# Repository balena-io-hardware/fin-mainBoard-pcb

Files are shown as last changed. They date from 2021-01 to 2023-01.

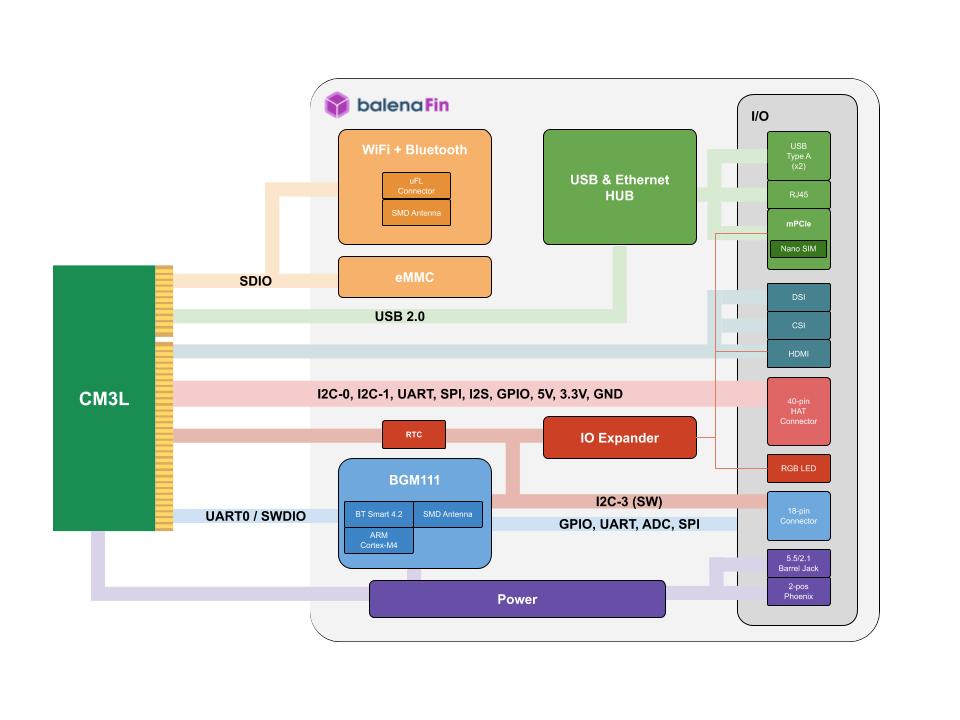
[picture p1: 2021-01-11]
Documentation/Block-diagram.jpg

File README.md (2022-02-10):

# balena-fin-pcb-legacy
balenaFin v1.x.x PCB repository

## OrCAD environment setup.

In order to get the proper poligon layout, the following parameters need to be set on "Global Dynamic Shape Parameters":

Under "Thermal relief connects" tab:
- Thru pin -> Full contact -> Minimum connections: 2
- Thru pin -> Full contact -> Maximum connections: 4
- SMD pin -> Orthogonal -> Maximum connections: 4
- SMD pin -> Orthogonal -> Maximum connections: 4
- Vias-> Full contact -> Maximum connections: 4
- Vias -> Full contact -> Maximum connections: 4
* In every case, "Best contact" should NOT be ticked.

- Select "Use fixed thermal width of": 0.2
* "Use xhatch thermal width" should be NOT ticked.

Under "Clearances" tab:
- Thru pin -> Thermal/ant -> Oversize value: 0.1
- SMD pin -> Thermal/ant -> Oversize value: 0.1
- Via -> Thermal/ant -> Oversize value: 0.1
- Line/cline -> (DRC) -> 0.0
- Text -> (DRC) -> 0.0
- Shape/rect -> (DRC) -> 0.0

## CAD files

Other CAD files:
Documentation/topographic/TOPOBOTTOM.dxf
Documentation/topographic/TOPOTOP.DXF
Source/bga-88-lead-round.psm
Source/bga-88-lead.psm
Source/bga-88-round.psm
Source/emi_filter.psm

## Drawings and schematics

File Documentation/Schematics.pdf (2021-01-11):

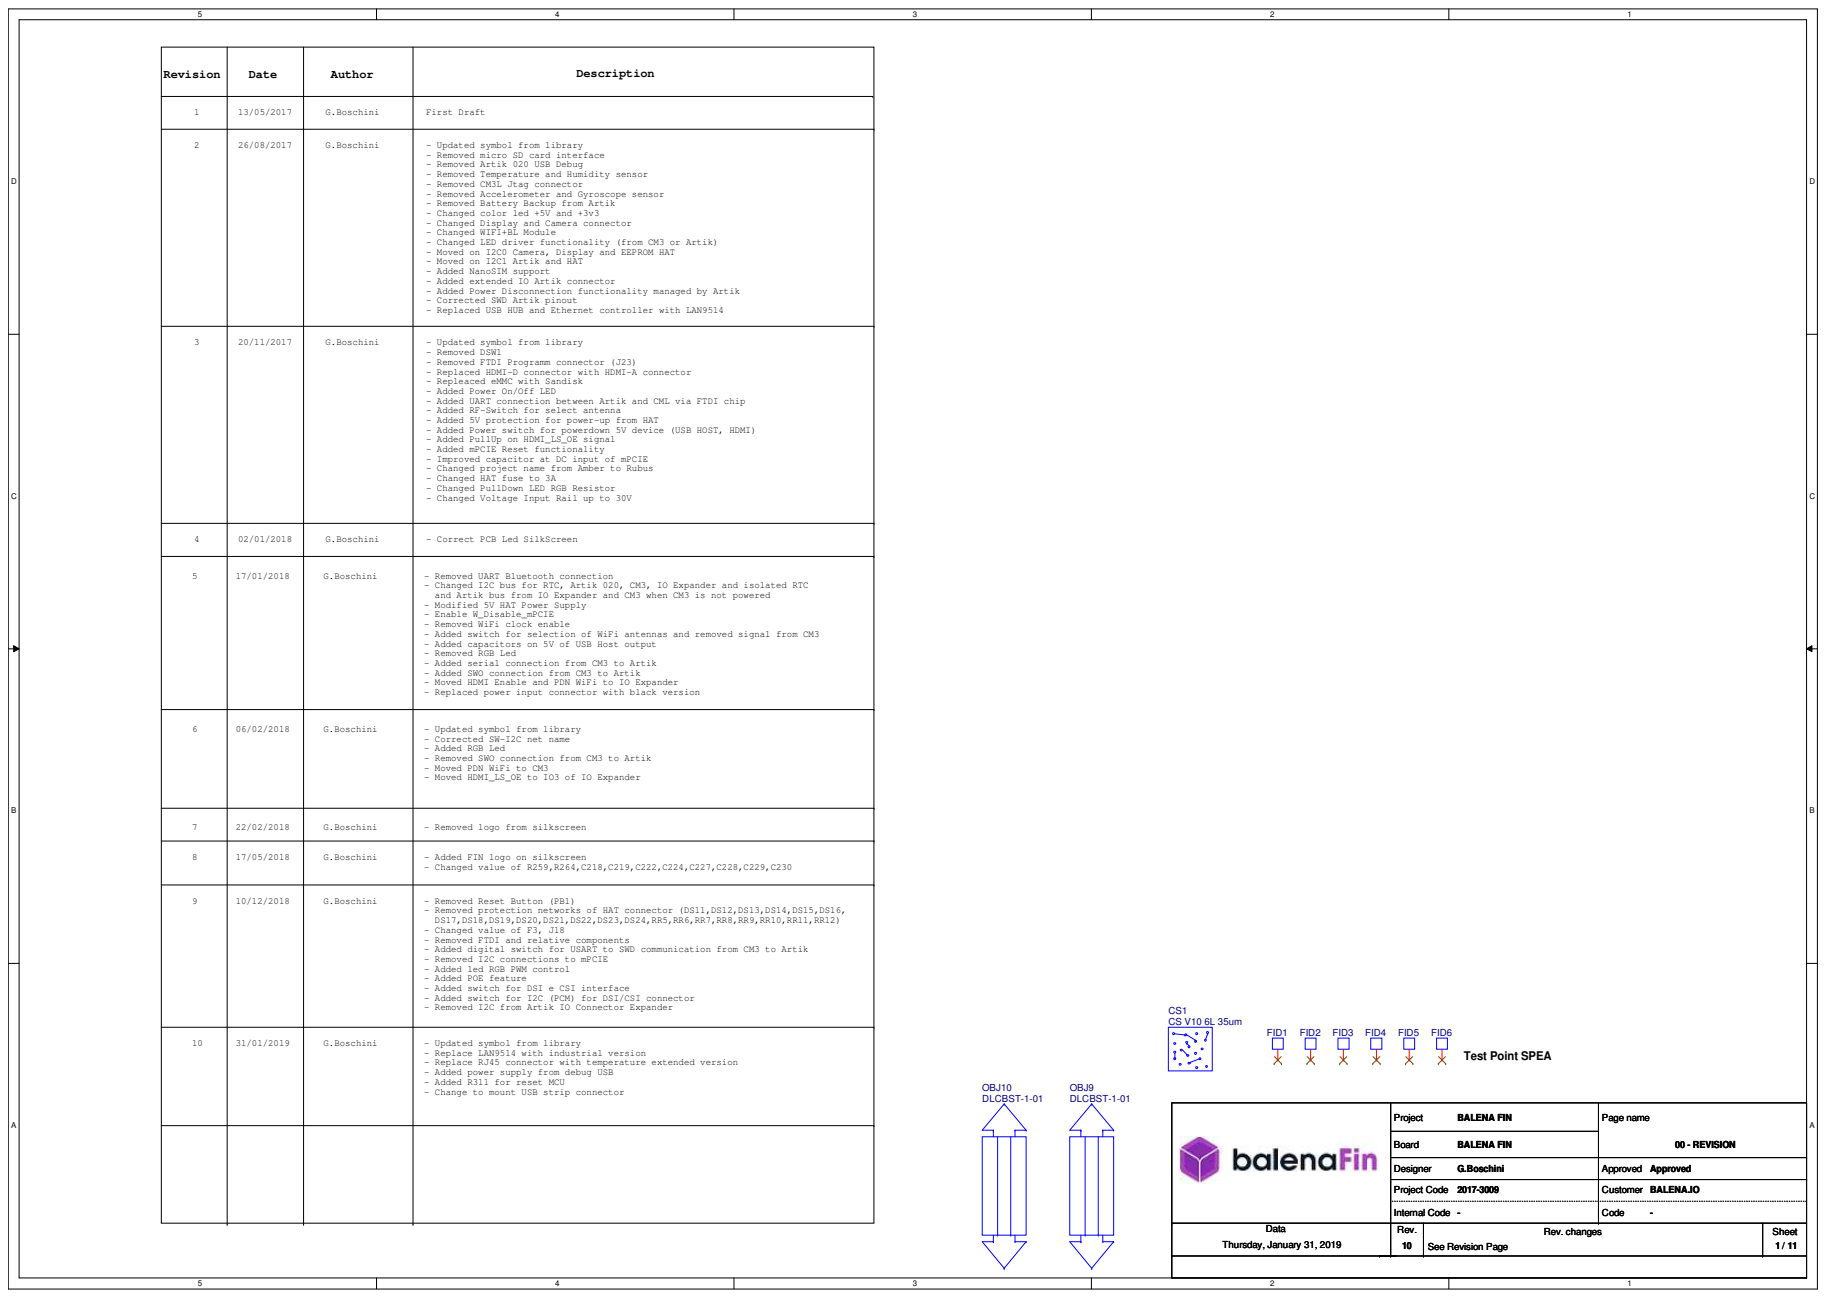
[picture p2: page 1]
Revision; Date; Author; Description; G.Boschini; First Draft; 2 G.Boschini 26/08/2017; - Updated symbol from library G.Boschini; G.Boschini 02/01/2018; - Correct PCB Led SilkScreen; - Removed UART Bluetooth connection G.Boschini; G.Boschini 06/02/2018; - Updated symbol from library; - Removed logo from silkscreen G.Boschini; - Removed Reset Button (PB1); 9 G.Boschini; - Added FIN logo on silkscreen; 8 G.Boschini; Rev.; Rev. changes; Sheet; Board; Project; Code; Page name; Data; Internal Code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

- Updated symbol from library
- Removed micro SD card interface
- Removed Artik 020 USB Debug
- Removed Temperature and Humidity sensor
- Removed CM3L Jtag connector
- Removed Accelerometer and Gyroscope sensor
- Removed Battery Backup from Artik
- Changed color led +5V and +3v3
- Changed Display and Camera connector
- Changed WIFI+BL Module
- Changed LED driver functionality (from CM3 or Artik)
- Moved on I2C0 Camera, Display and EEPROM HAT
- Moved on I2C1 Artik and HAT
- Added NanoSIM support
- Added extended IO Artik connector
- Added Power Disconnection functionality managed by Artik
- Corrected SWD Artik pinout
- Replaced USB HUB and Ethernet controller with LAN9514

- Removed DSW1
- Removed FTDI Programm connector (J23)
- Replaced HDMI-D connector with HDMI-A connector
- Repleaced eMMC with Sandisk
- Added Power On/Off LED
- Added UART connection between Artik and CML via FTDI chip
- Added RF-Switch for select antenna
- Added 5V protection for power-up from HAT
- Added Power switch for powerdown 5V device (USB HOST, HDMI)
- Added PullUp on HDMI_LS_OE signal
- Added mPCIE Reset functionality
- Improved capacitor at DC input of mPCIE
- Changed project name from Amber to Rubus
- Changed HAT fuse to 3A
- Changed PullDown LED RGB Resistor
- Changed Voltage Input Rail up to 30V

- Changed I2C bus for RTC, Artik 020, CM3, IO Expander and isolated RTC
and Artik bus from IO Expander and CM3 when CM3 is not powered
- Modified 5V HAT Power Supply
- Enable W_Disable_mPCIE
- Removed WiFi clock enable
- Added switch for selection of WiFi antennas and removed signal from CM3
- Added capacitors on 5V of USB Host output
- Removed RGB Led
- Added serial connection from CM3 to Artik
- Added SWO connection from CM3 to Artik
- Moved HDMI Enable and PDN WiFi to IO Expander
- Replaced power input connector with black version

- Corrected SW-I2C net name
- Added RGB Led
- Removed SWO connection from CM3 to Artik
- Moved PDN WiFi to CM3
- Moved HDMI_LS_OE to IO3 of IO Expander

- Changed value of R259,R264,C218,C219,C222,C224,C227,C228,C229,C230

- Removed protection networks of HAT connector (DS11,DS12,DS13,DS14,DS15,DS16,
- Changed value of F3, J18
- Removed FTDI and relative components
- Added digital switch for USART to SWD communication from CM3 to Artik
- Removed I2C connections to mPCIE
- Added led RGB PWM control
- Added POE feature
- Added switch for DSI e CSI interface
- Added switch for I2C (PCM) for DSI/CSI connector
- Removed I2C from Artik IO Connector Expander

- Replace LAN9514 with industrial version
- Replace RJ45 connector with temperature extended version
- Added power supply from debug USB
- Added R311 for reset MCU
- Change to mount USB strip connector

Test Point SPEA

Designer Designer Designer G.Boschini G.Boschini G.Boschini | Approved Approved Approved

Project Code Project Code Project Code 2017-3009 2017-3009 2017-3009 | Customer Customer Customer BALENA.IO BALENA.IO BALENA.IO

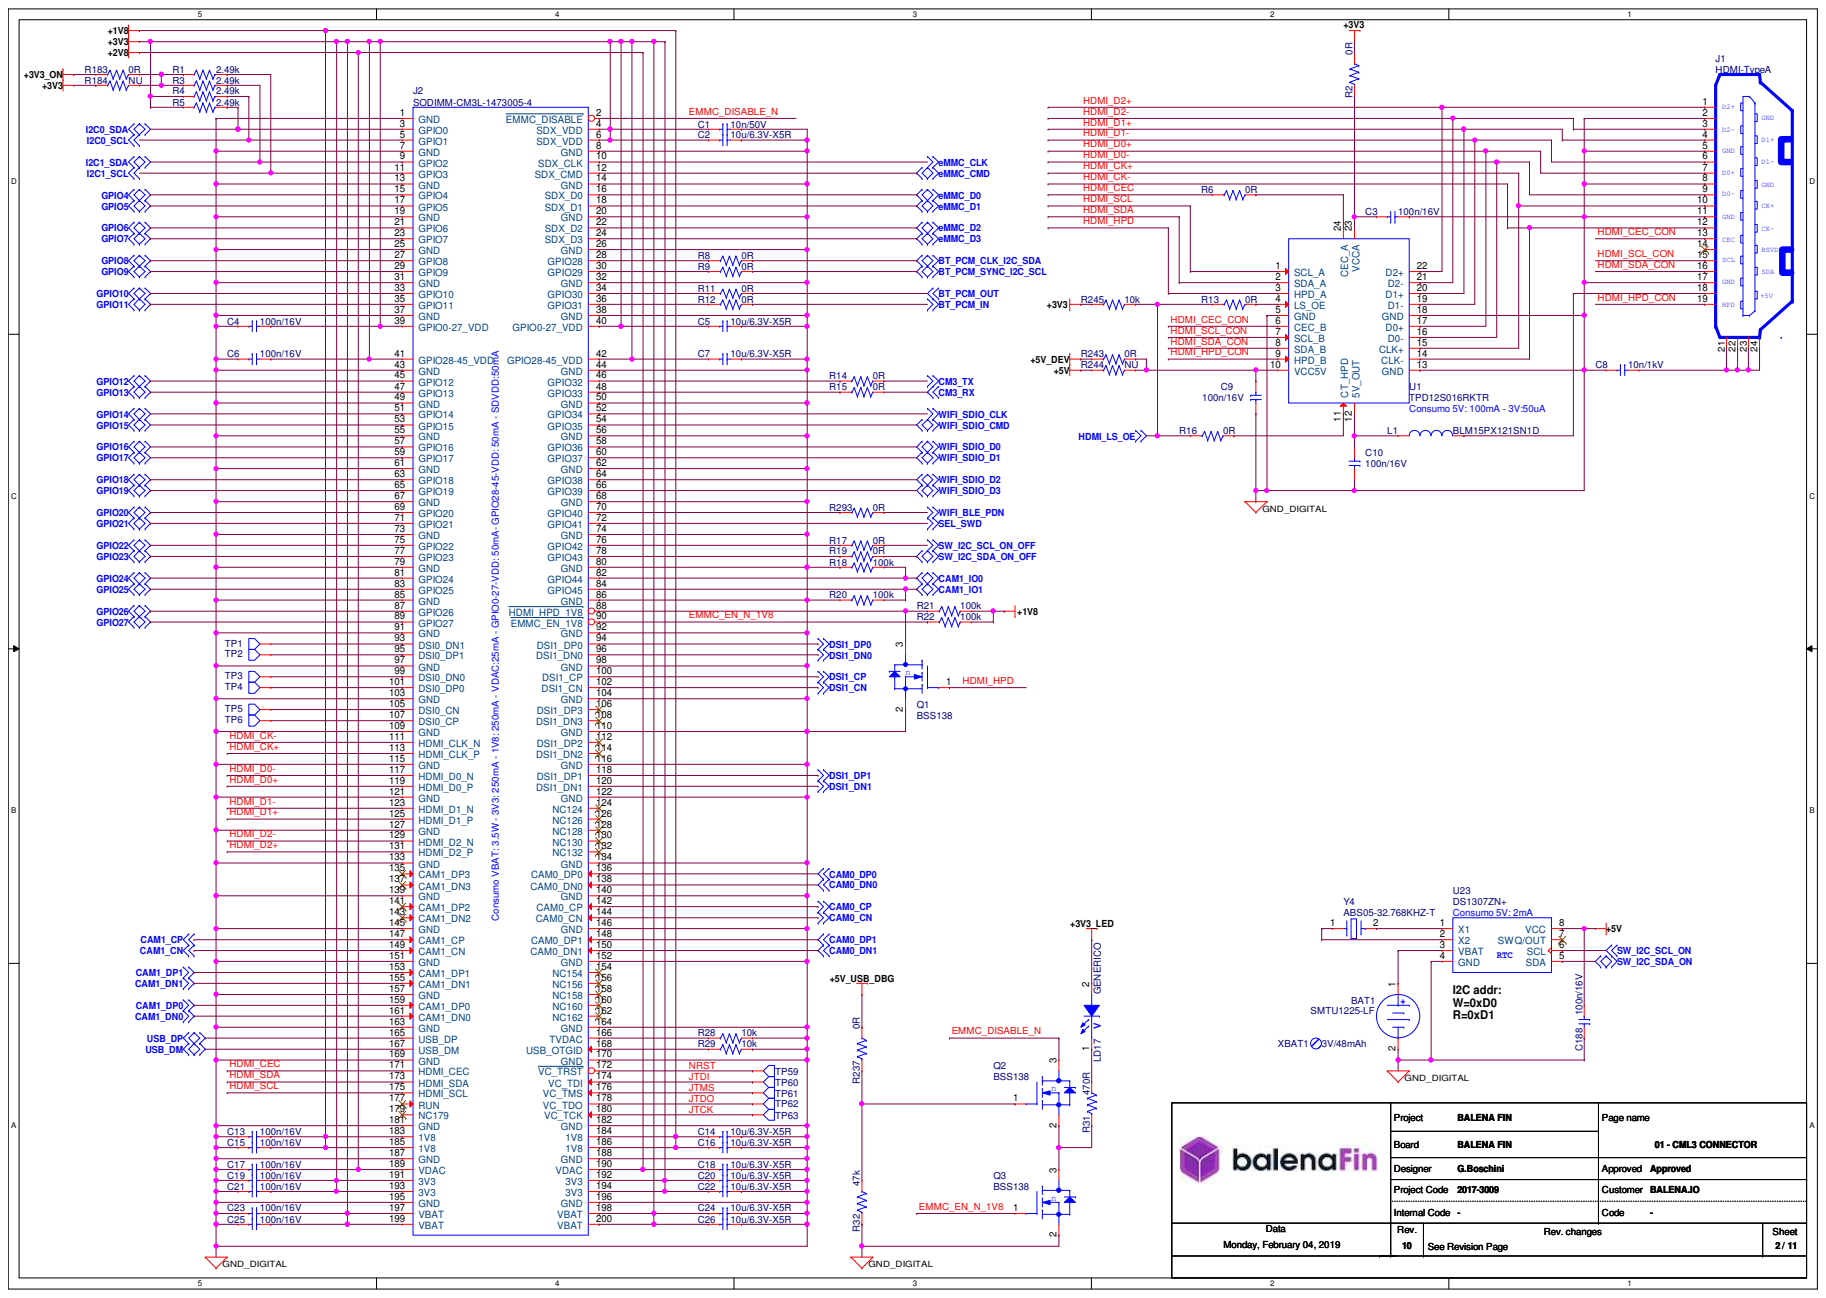
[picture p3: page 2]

11
12

HDMI_CEC_CON 13

Consumo VBAT: 3.5W - 3V3: 250mA - 1V8: 250mA - VDAC:25mA - GPIO0-27-VDD: 50mA- GPIO28-45-VDD: 50mA - SDVDD:50mA

Designer Designer Designer G.Boschini G.Boschini G.Boschini | Approved Approved Approved

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

Internal Code Internal Code Internal Code --- | Code Code Code ---
Rev. Rev. Rev. 10 10 10 | Rev. changes Rev. changes Rev. changes See Revision Page See Revision Page See Revision Page | Sheet Sheet Sheet / / / 112 112 112

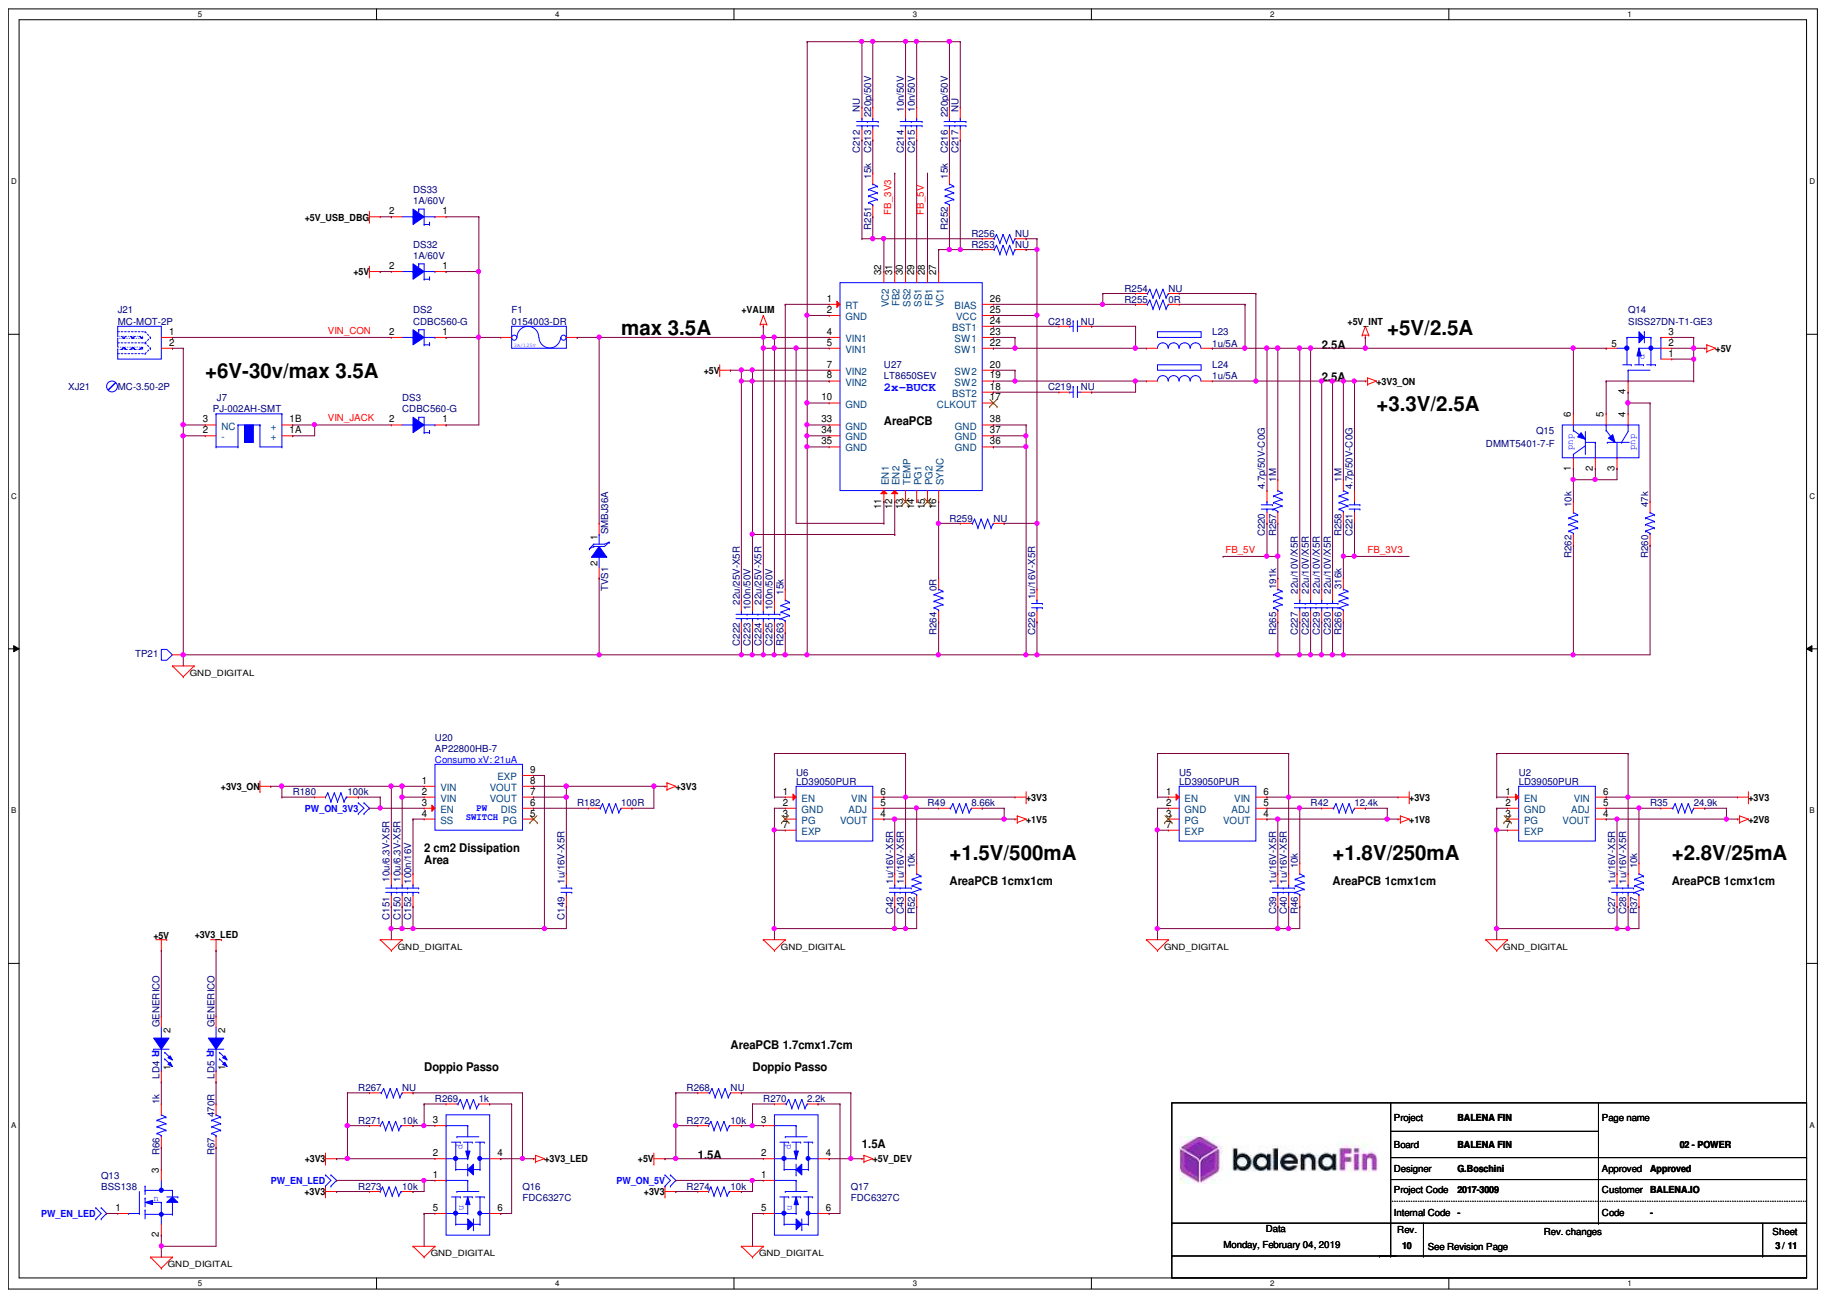
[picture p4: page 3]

GND 10

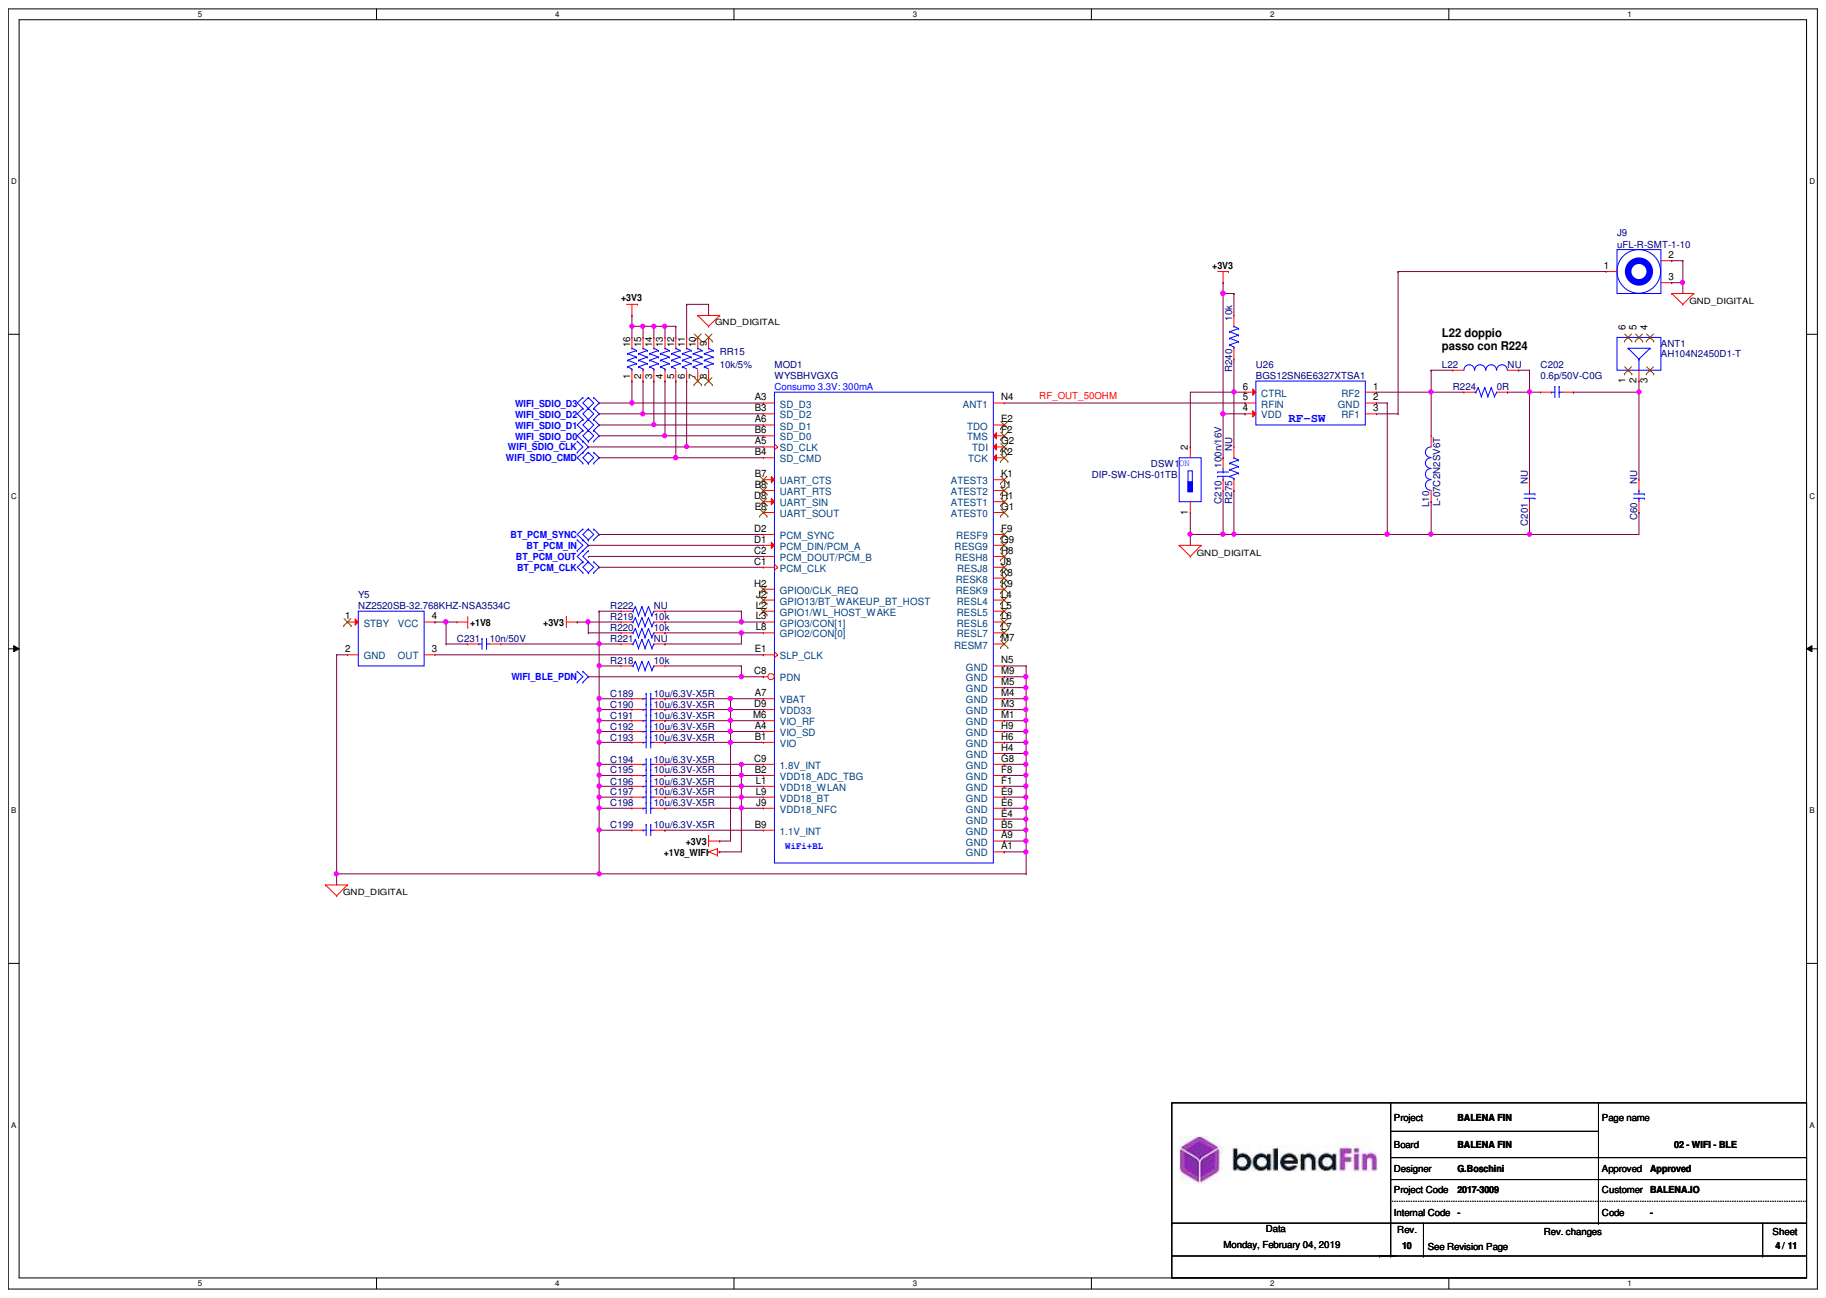
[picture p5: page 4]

Designer Designer Designer G.Boschini G.Boschini G.Boschini | Approved Approved Approved

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

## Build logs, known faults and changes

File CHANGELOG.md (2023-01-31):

# Change Log

All notable changes to this project will be documented in this file
automatically by Versionist. DO NOT EDIT THIS FILE MANUALLY!
This project adheres to [Semantic Versioning](http://semver.org/).

# v2.0.0
## (2023-01-31)

* Add copyright and licensing notice [Heath Raftery]
* Add Flowzone [zisis00]
* Added assembly pin 1 for U34 [Nicolas Tzovanis]
* Added english names for components [Nicolas Tzovanis]
* Fixed database and BoM for release [Nicolas Tzovanis]
* Finish routing changes [Nicolas Tzovanis]
* Schematic changes for replacing LT8650S for LTM8024 [Nicolas Tzovanis]
* Added instructions for global shape parameters. [Nicolas Tzovanis]
* Added global settings to fix polygons [Nicolas Tzovanis]
* Generated v1.1.1 to fix thermal issue [Nicolas Tzovanis]
* Changed PCB version to V12 [Nicolas Tzovanis]
* Changed TCE0806G-900-2P-T2 for LCFE080602G900TG [Nicolas Tzovanis]
* Added cached files to library [Nicolas Tzovanis]
* Added files for hardware v1.1.0 (v10) [Nicolas Tzovanis]
* Adding v1.1.0 V9 [Nicolas Tzovanis]

# v1.0.0
## (2022-11-09)

* Add Flowzone [zisis00]
* Added assembly pin 1 for U34 [Nicolas Tzovanis]
* Added english names for components [Nicolas Tzovanis]
* Fixed database and BoM for release [Nicolas Tzovanis]
* Finish routing changes [Nicolas Tzovanis]
* Schematic changes for replacing LT8650S for LTM8024 [Nicolas Tzovanis]
* Added instructions for global shape parameters. [Nicolas Tzovanis]
* Added global settings to fix polygons [Nicolas Tzovanis]
* Generated v1.1.1 to fix thermal issue [Nicolas Tzovanis]
* Changed PCB version to V12 [Nicolas Tzovanis]
* Changed TCE0806G-900-2P-T2 for LCFE080602G900TG [Nicolas Tzovanis]
* Added cached files to library [Nicolas Tzovanis]
* Added files for hardware v1.1.0 (v10) [Nicolas Tzovanis]
* Adding v1.1.0 V9 [Nicolas Tzovanis]
* Final v1.0.0 version [Nicolas Tzovanis]
* Added V1.0.0 release candidate 3 [Nicolas Tzovanis]
* Added changes for v1.0.0 Release Candidate 2 [Nicolas Tzovanis]
* Adding v1.0.0 release candidate 1 [Nicolas Tzovanis]
* Loading docs for v0.9.0 [Nicolas Tzovanis]
* Adding gitignore [Nicolas Tzovanis]

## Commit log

2021-01-07 Added changes for v1.0.0 Release Candidate 2
    Change-type: minor
    [TOPOBOTTOM.dxf, TOPOTOP.dxf]
2021-01-07 Added V1.0.0 release candidate 3
    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
    [TOPOBOTTOM.dxf, TOPOTOP.dxf]
2021-01-07 Added files for hardware v1.1.0 (v10)
    Change-type: patch
    [TOPOBOTTOM.dxf, TOPOTOP.DXF]
2021-05-11 Added alternatives for obsolete components
    [BOM_20173009_BALENA-FIN_V11_pblc.xlsx, cases.cfg, emi_filter.psm]
2021-05-13 Changed PCB version to V12
    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
2021-05-24 Added global settings to fix polygons
    In Global Dynamic Shape parameters:
    - In Thermal relief connects:
    - Set SMD pins to "Orthogonal"
    - Set "Use fixed thermal width of:" to 0.2
    - In Clearances
    - Set "Thru pin", "SMD pin" and "Via: to "Thermal" and their respective "Oversize values" to 0.1
    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
2021-05-24 Cleaning up files
    [BOM_20173009_BALENA-FIN_V11_pblc.xlsx]
2021-09-09 Schematic changes for replacing LT8650S for LTM8024
    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
    [bga-88-lead-round.psm, bga-88-lead.psm, bga-88-round.psm]
2021-09-30 Fixed database and BoM for release
    Translated all component information to English
    Fixed database and shape issues to be able to create a release.
    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
2021-11-10 Added assembly pin 1 for U34
    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
    [bga-88-round.psm]
2022-11-09 Add Flowzone
    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
2023-01-31 Add Solderpad Hardware License
